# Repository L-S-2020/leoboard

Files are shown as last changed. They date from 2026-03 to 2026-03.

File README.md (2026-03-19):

# Leoboard
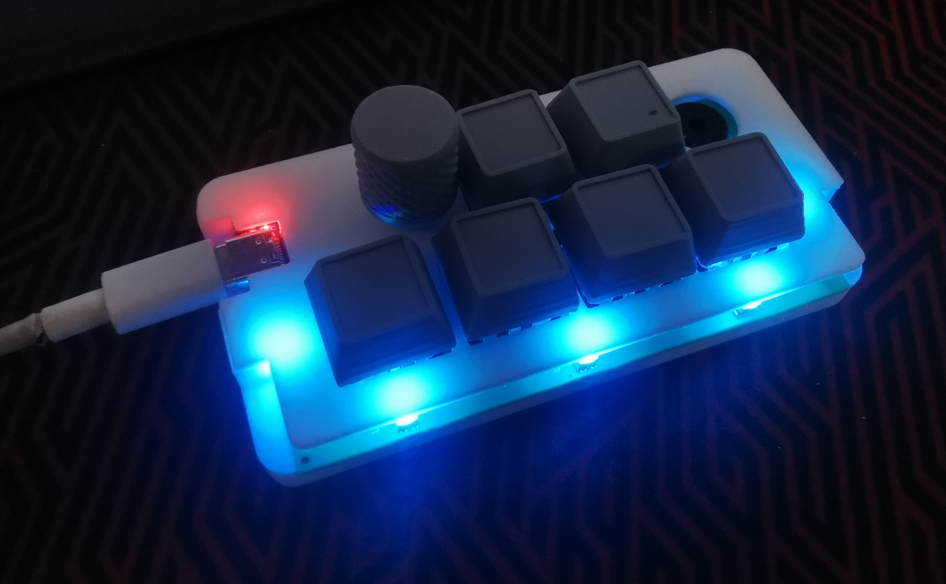
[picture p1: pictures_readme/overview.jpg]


A makroboard I designed as a christmas present and my first project using 3d printing / cad design.
You can find the case design on onshape under: 
https://cad.onshape.com/documents/f016138659585157d187dc39/w/5da7c9f47346b58de636040e/e/736dc8079a6dc26abaf89305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

## Features
- 6 MX Style switches
- buzzer (for sound)
- rotary encoder
- rgb leds 
- rp2040 based

Note: The code folder also includes kmk and the necessary addons, so it can be directly flashed to the rp2040.

## Standard key binds
The board has 3 switchable layers:
|Layer| Rotary button | Rotary encoder | Button 1 | Button 2 | Button 3 | Button 4 | Button 5 | Button 6 |
|--|--|--|--|--|--|--|--|--|
| 1 (normal) | Mute | Volume | Play/ Pause | Next song | Previous song | Win+Shift+S | Task manager | Lock pc |
|2 (gaming) |Discord mute| Volume | Mute | Discord audio off | Medal save clip | Screenshot | M | I |
|3 (premiere pro) | \ | Seek through frames | Add cut | Delete clip | Zoom in | Zoom out | Undo | Redo |
|Setings| must be hold down | -- | Layer 1 | Layer 2 | Layer 3 | LED on/off | LED breathe animation |LED rainbow animation |

## The story
One day as I was editing a video for the video club at my school (check out the [yt channel](https://www.youtube.com/@gsgwaldkirch4155)), I was annoyed by the standard key assignments of Premiere Pro. Especially using the arrow keys to seek through frames manually (i.e. for finding the excact startframe of a clip) is a really slow process, so I thought, wouldn't it be cool to have a rotary knob for that and then also to have a special key set for directly placing cuts and zooming in the timeline? 

So I the idea to design my own macroboard was born. I found a nice starting tutorial on [the hackclub blueprint website](https://blueprint.hackclub.com/), which showed the ground ideas of macroboard design.
As it was just two weeks before christmas back then, I thought it would also be cool to use the board as a christmas present.

So I got started with the pcb design using kicad. The design itself is based on the seed xiao rp2040 devboard, as it is the perfect size and also quite cheap. Additionally to my initial requirements (switches and rotary encoder), I came up with the idea to also add leds for light and a buzzer for playing startup sounds.

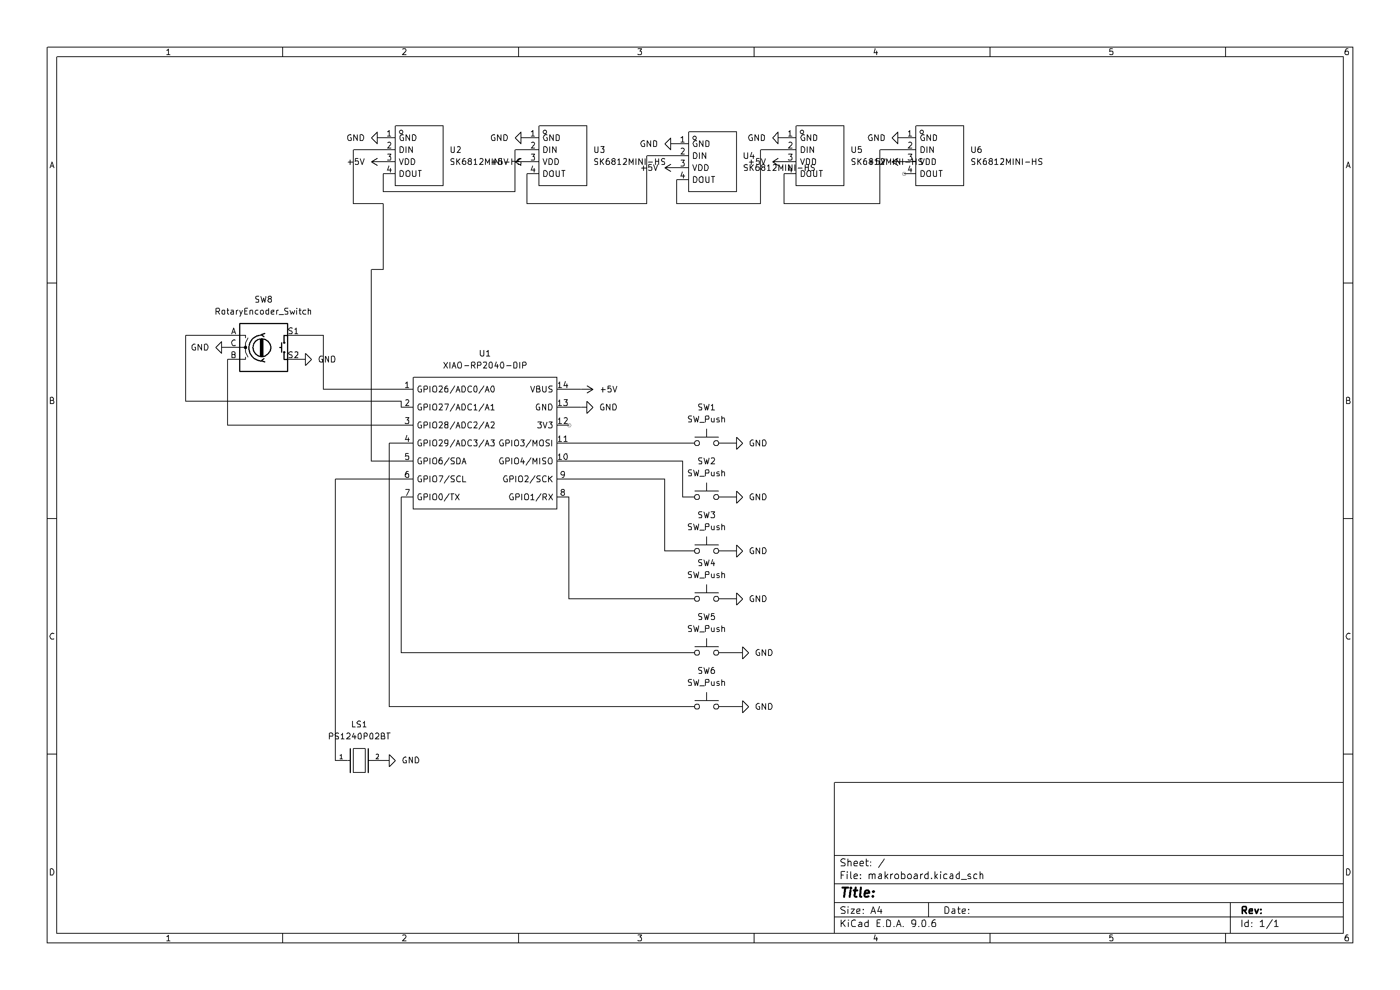
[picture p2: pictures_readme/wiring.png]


Then I designed the pcb board and searched in the jlcpcb parts library for suiting (and cheap) parts. 

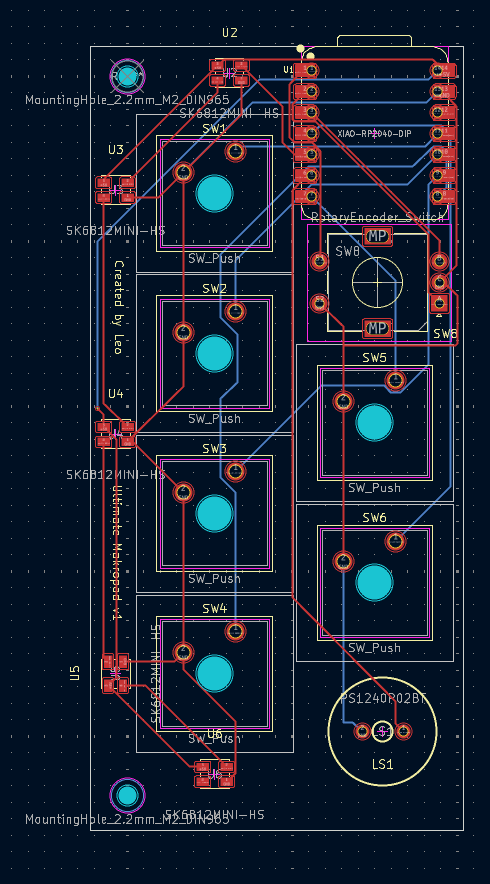
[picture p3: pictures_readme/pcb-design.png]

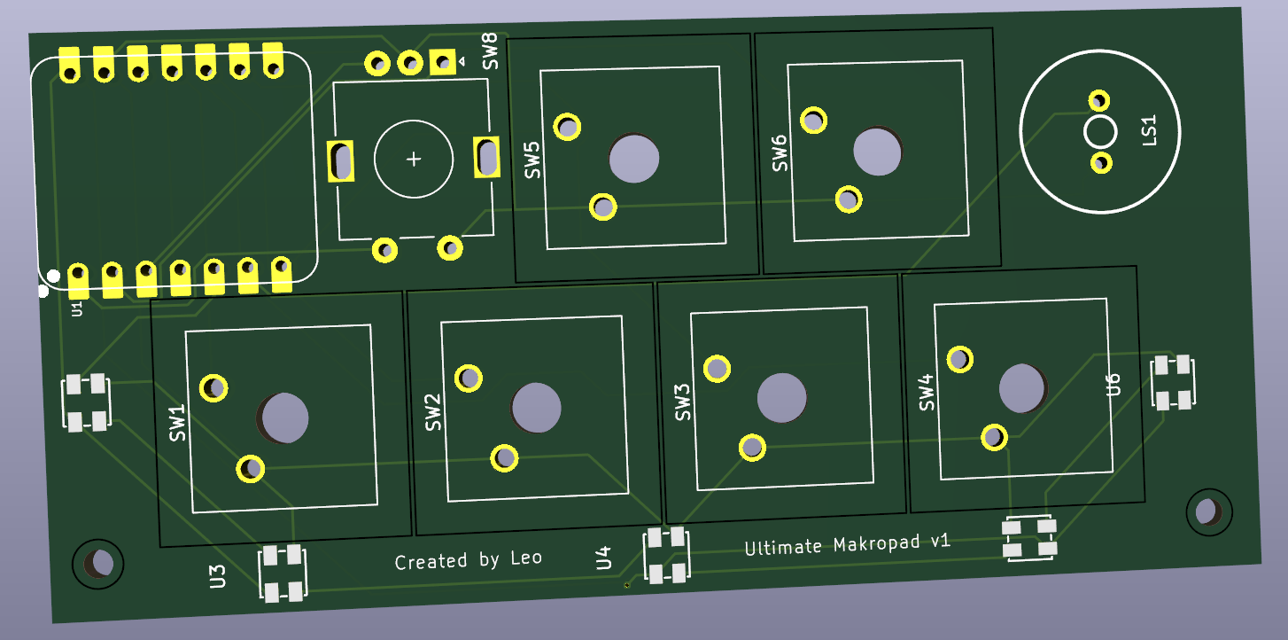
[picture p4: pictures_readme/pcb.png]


As the order was on its way, I started designing the case using onshape.

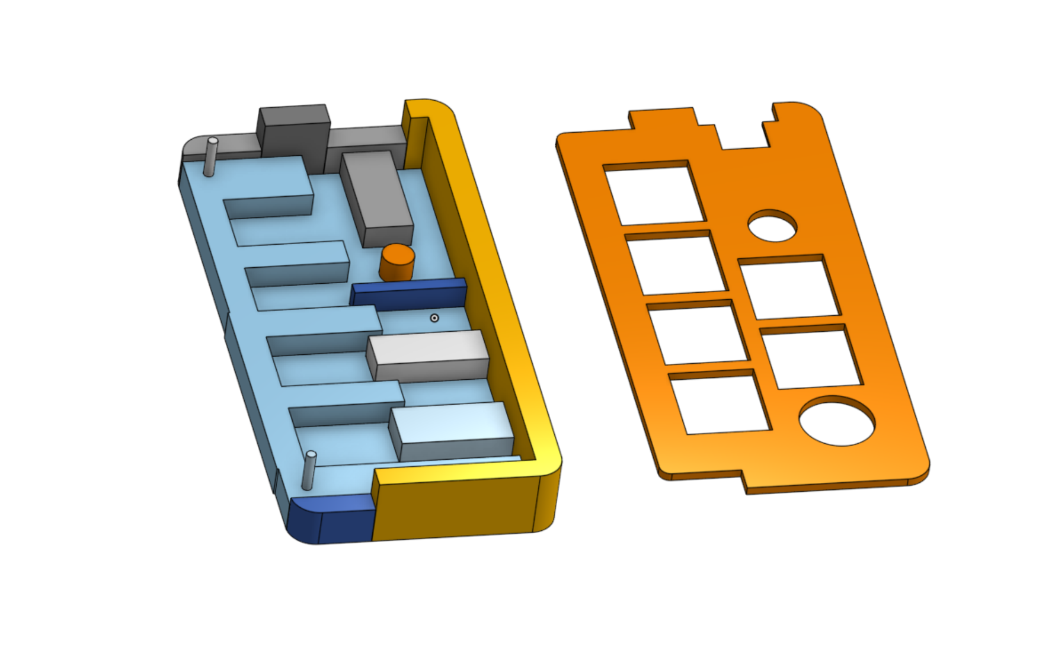
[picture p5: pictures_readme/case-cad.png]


I also created an assembled model in onshape, to test the dimensions.

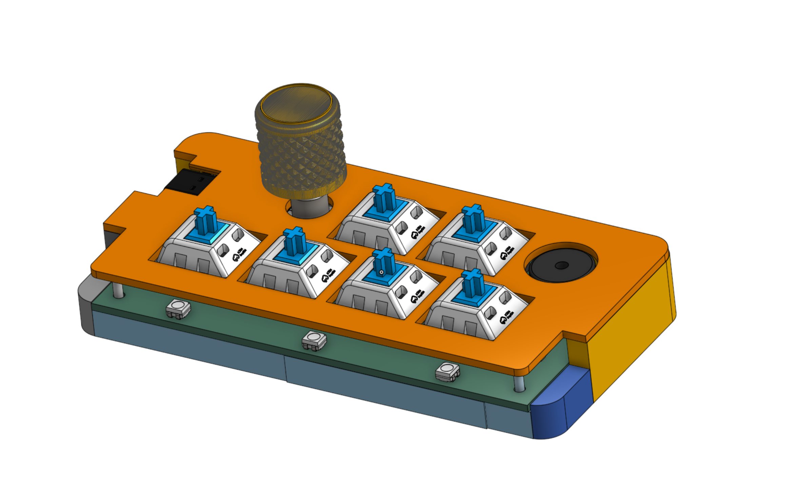
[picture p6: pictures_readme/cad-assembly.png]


After printing and assembling the final macropads, I learned that, it's not good to make the inner dimensions of your case exactly like the dimensions of your board ;) , but fortunately, I printed everything in pla, so after some heating using a hair dryer, I could fit the pcb inside.

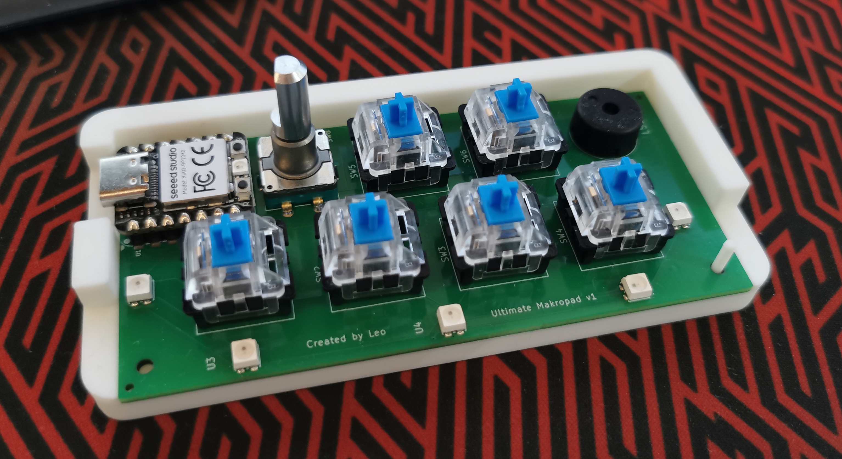
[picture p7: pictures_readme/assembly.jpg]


I then wrote a script for it, using kmk, as I liked the idea of being able to quickly change some configurations, without having to recompile. 
[@SillyGoose123](https://github.com/SillyGoose123) is also currently working on a more powerful, rust-based firmware for the board with a web based settings interface, check it out [here](https://github.com/SillyGoose123/MacroBoard).

##
A big thanks to my cs teacher for letting me print out the cases using the 3dprinter in his office and to [@SillyGoose123](https://github.com/SillyGoose123) for printing out the keycaps.

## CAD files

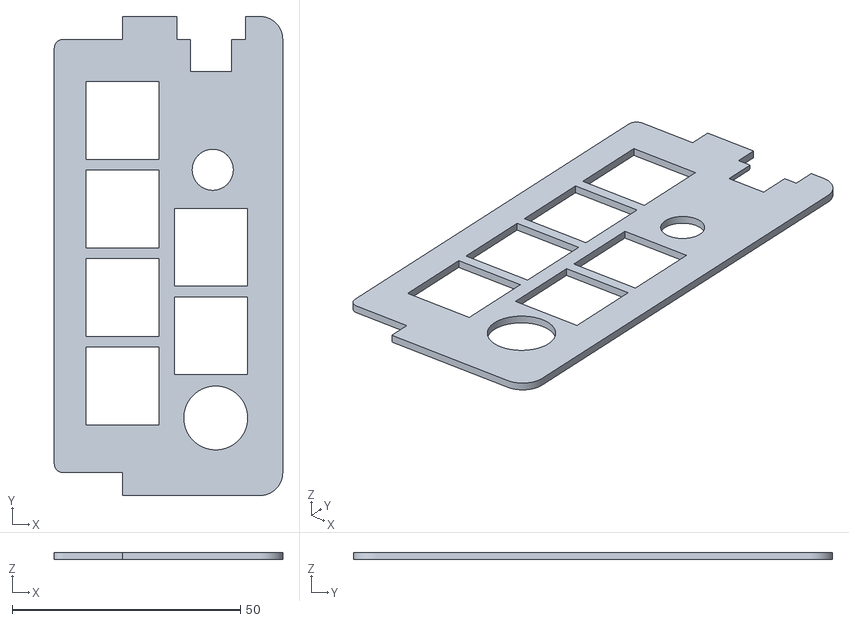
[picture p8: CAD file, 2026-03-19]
cad/top.stl
50.1 x 105.0 x 1.60

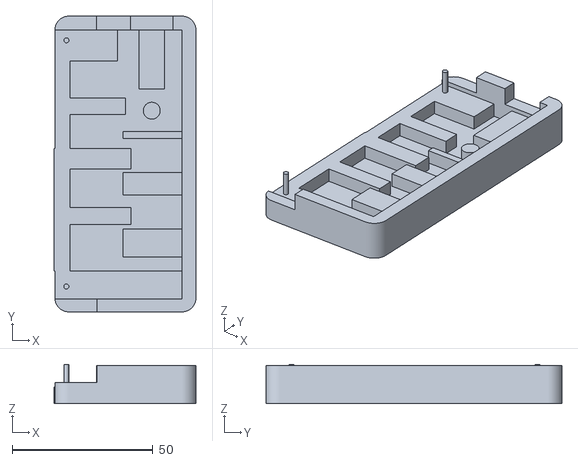
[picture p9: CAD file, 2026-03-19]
cad/bottom.stl
50.4 x 105.0 x 14.0

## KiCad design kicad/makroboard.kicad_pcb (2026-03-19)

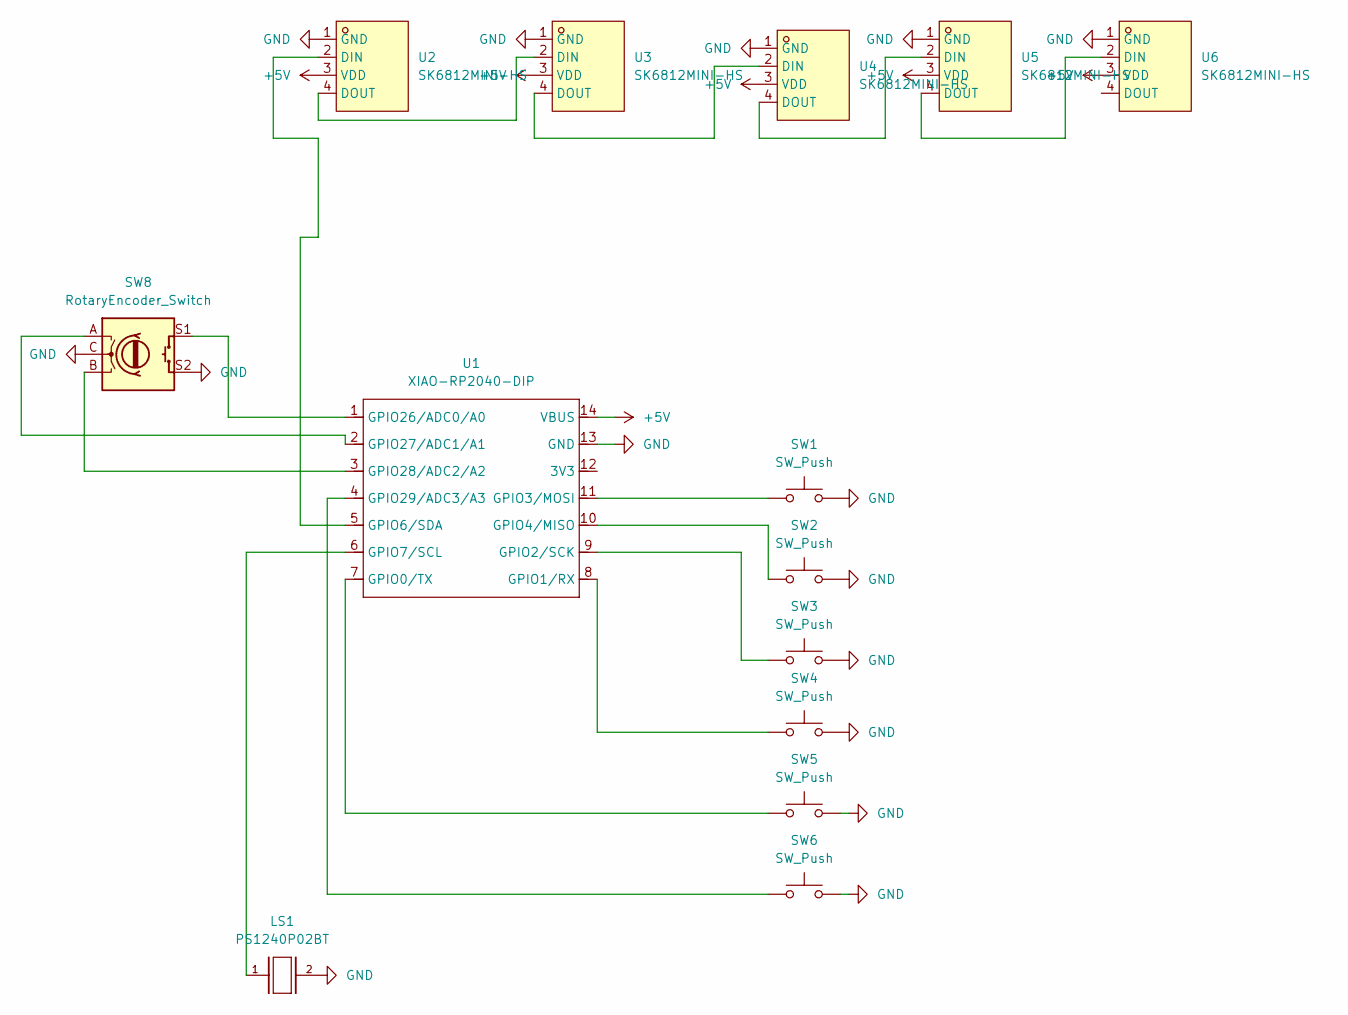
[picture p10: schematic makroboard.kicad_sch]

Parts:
LS1: PS1240P02BT; XDCR_PS1240P02BT
SW1, SW2, SW3, SW4, SW5, SW6: SW_Push; SW_Cherry_MX_1.00u_Plate
SW8: RotaryEncoder_Switch; RotaryEncoder_Alps_EC11E-Switch_Vertical_H20mm
U1: XIAO-RP2040-DIP
U2, U3, U4, U5, U6: SK6812MINI-HS; LED-SMD_4P-L3.5-W3.5-BR_SK6812MINI-HS; LCSC Part C2922787

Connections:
+5V: U1.14 (VBUS), U2.3 (VDD), U3.3 (VDD), U4.3 (VDD), U5.3 (VDD), U6.3 (VDD)
GND: LS1.2, SW1.2, SW2.2, SW3.2, SW4.2, SW5.2, SW6.2, SW8.C, SW8.S2, U1.13 (GND), U2.1 (GND), U3.1 (GND), U4.1 (GND), U5.1 (GND), U6.1 (GND)
unnamed: SW5.1, U1.7 (GPIO0/TX)
unnamed: SW4.1, U1.8 (GPIO1/RX)
unnamed: SW3.1, U1.9 (GPIO2/SCK)
unnamed: SW1.1, U1.11 (GPIO3/MOSI)
unnamed: SW2.1, U1.10 (GPIO4/MISO)
unnamed: U1.5 (GPIO6/SDA), U2.2 (DIN)
unnamed: LS1.1, U1.6 (GPIO7/SCL)
unnamed: SW8.S1, U1.1 (GPIO26/ADC0/A0)
unnamed: SW8.A, U1.2 (GPIO27/ADC1/A1)
unnamed: SW8.B, U1.3 (GPIO28/ADC2/A2)
unnamed: SW6.1, U1.4 (GPIO29/ADC3/A3)
unnamed: U2.4 (DOUT), U3.2 (DIN)
unnamed: U3.4 (DOUT), U4.2 (DIN)
unnamed: U4.4 (DOUT), U5.2 (DIN)
unnamed: U5.4 (DOUT), U6.2 (DIN)

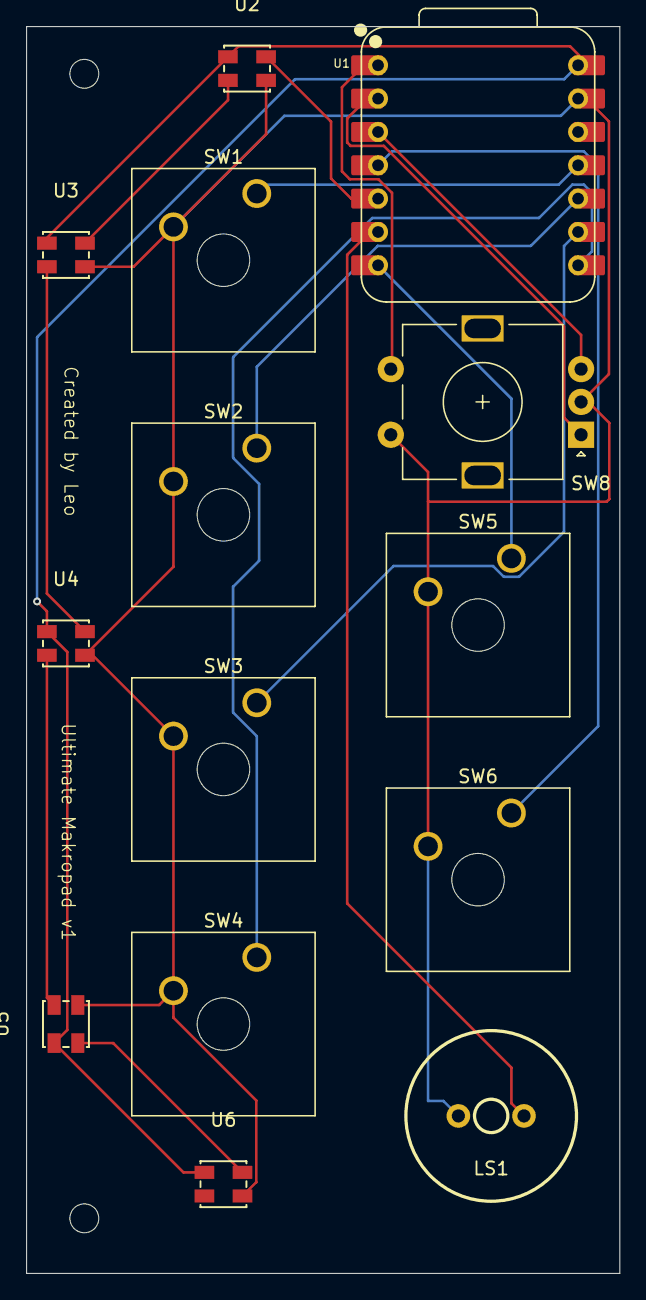
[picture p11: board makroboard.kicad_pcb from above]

Board: 2 copper layers, 45.2 x 95.0 mm, 15 parts (0 on the bottom side), 17 nets.

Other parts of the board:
MT: MountingHole_2.2mm_M2_DIN965

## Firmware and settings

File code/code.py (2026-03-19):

import time
import board
import digitalio
import pwmio

from kmk.kmk_keyboard import KMKKeyboard
from kmk.scanners.keypad import KeysScanner
from kmk.keys import KC
from kmk.modules.layers import Layers
from kmk.modules.macros import Macros
from kmk.modules.encoder import EncoderHandler
from kmk.extensions.media_keys import MediaKeys
from kmk.extensions.RGB import RGB
from kmk.extensions.rgb import AnimationModes
from kmk.extensions import Extension

# ---------------- Layer IDs ----------------
L_NORMAL   = 0
L_GAMING   = 1
L_PREMIERE = 2
L_FN       = 3

# ---------------- Buzzer (simple, reliable) ----------------
import time
import pwmio
from kmk.extensions import Extension

class _BuzzerPlayer:
    def __init__(self, pin, duty_on=2**15):
        self.pin = pin
        self.duty_on = duty_on
        self.pwm = None
        self.seq = None
        self.i = 0
        self.until = 0.0
        self.playing = False
        self._init_pwm()

    def _init_pwm(self):
        if self.pwm:
            try:
                self.pwm.deinit()
            except Exception:
                pass
        self.pwm = pwmio.PWMOut(self.pin, variable_frequency=True, duty_cycle=0)

    def stop(self):
        # hard stop
        try:
            self.pwm.duty_cycle = 0
        except Exception:
            pass
        self.playing = False
        self.seq = None
        self.i = 0

    def play(self, seq):
        self.seq = list(seq)
        self.i = 0
        self.playing = True
        self._start_step()

    def _start_step(self):
        if not self.seq or self.i >= len(self.seq):
            self.stop()
            return
        freq, dur_ms = self.seq[self.i]
        if freq and freq > 0:
            self.pwm.frequency = int(freq)
            self.pwm.duty_cycle = self.duty_on
        else:
            self.pwm.duty_cycle = 0
        self.until = time.monotonic() + dur_ms / 1000.0

    def tick(self):
        if not self.playing:
            return
        if time.monotonic() >= self.until:
            self.i += 1
            self._start_step()
    
    def after_matrix_scan(self, sandbox):
        return
    
    def before_hid_send(self, sandbox):
        return
        
    def after_hid_send(self, sandbox):
        return

def _beep(n, freq=2200, on_ms=55, off_ms=55):
    out = []
    for k in range(n):
        out.append((freq, on_ms))
        if k != n - 1:
            out.append((0, off_ms))
    return out

def _startup():
    return [(1600, 40), (0, 25), (2400, 60), (0, 20)]

class LayerLEDs(Extension):
    def __init__(self, led_r, led_g, led_b, active_low=True):
        self.led_r, self.led_g, self.led_b = led_r, led_g, led_b
        self.active_low = active_low
        self.last = None

    def during_bootup(self, keyboard):
        # must exist or extension gets removed [page:0]
        self._all_off()

    def _on(self, led):
        led.value = False if self.active_low else True

    def _off(self, led):
        led.value = True if self.active_low else False

    def _all_off(self):
        self._off(self.led_r)
        self._off(self.led_g)
        self._off(self.led_b)

    def _set(self, base):
        self._all_off()
        if base == 0:
            self._on(self.led_r)
        elif base == 1:
            self._on(self.led_g)
        elif base == 2:
            self._on(self.led_b)

    def before_matrix_scan(self, sandbox):
        # sandbox.active_layers is refreshed every loop [page:0]
        layers = sandbox.active_layers or [0]
        base_candidates = [l for l in layers if l in (0, 1, 2)]
        base = max(base_candidates) if base_candidates else 0
        if base != self.last:
            self.last = base
            self._set(base)
    
    def after_matrix_scan(self, sandbox):
        return
    
    def before_hid_send(self, sandbox):
        return
        
    def after_hid_send(self, sandbox):
        return

class BuzzerSounds(Extension):
    def __init__(self, buzzer_pin):
        self.player = _BuzzerPlayer(buzzer_pin)
        self.last_base = None
        self.did_startup = False

    def during_bootup(self, keyboard):
        # must exist or extension gets removed [page:0]
        self.player.stop()
        self.last_base = None
        self.did_startup = False

    def before_matrix_scan(self, sandbox):
        # Always tick audio here (runs each loop) [page:0]
        self.player.tick()

        # Start-up sound once (first loop after boot)
        if not self.did_startup:
            self.did_startup = True
            self.player.play(_startup())
            return

        # Layer-change sound (base layer only)
        layers = sandbox.active_layers or [0]
        base_candidates = [l for l in layers if l in (0, 1, 2)]
        base = max(base_candidates) if base_candidates else 0

        if base != self.last_base:
            self.last_base = base
            self.player.play(_beep(base + 1))
    
    def after_matrix_scan(self, sandbox):
        return
    
    def before_hid_send(self, sandbox):
        return
        
    def after_hid_send(self, sandbox):
        return



import board
import digitalio

from kmk.kmk_keyboard import KMKKeyboard
from kmk.scanners.keypad import KeysScanner
from kmk.keys import KC
from kmk.modules.layers import Layers
from kmk.modules.macros import Press, Release, Tap, Macros
from kmk.modules.encoder import EncoderHandler
from kmk.extensions.media_keys import MediaKeys
from kmk.extensions.RGB import RGB

# ---------------- Layers ----------------
L_NORMAL   = 0
L_GAMING   = 1
L_PREMIERE = 2
L_FN       = 3

# ---------------- Macros ----------------
macros = Macros()

WIN_SHIFT_S = KC.MACRO(
    Press(KC.LGUI),
    Press(KC.LSFT),
    Tap(KC.S),
    Release(KC.LSFT),
    Release(KC.LGUI),
)

TASK_MANAGER = KC.MACRO(
    Press(KC.LCTL),
    Press(KC.LSFT),
    Tap(KC.ESC),
    Release(KC.LSFT),
    Release(KC.LCTL),
)

LOCK_PC = KC.MACRO(
    Press(KC.LGUI),
    Tap(KC.L),
    Release(KC.LGUI),
)

CTRL_SHIFT_M = KC.MACRO(
    Press(KC.LCTL),
    Press(KC.LSFT),
    Tap(KC.M),
    Release(KC.LSFT),
    Release(KC.LCTL),
)

CTRL_SHIFT_D = KC.MACRO(
    Press(KC.LCTL),
    Press(KC.LSFT),
    Tap(KC.D),
    Release(KC.LSFT),
    Release(KC.LCTL),
)

ALT_F10 = KC.MACRO(
    Press(KC.LALT),
    Tap(KC.F10),
    Release(KC.LALT),
)

CTRL_K = KC.MACRO(
    Press(KC.LCTL),
    Tap(KC.K),
    Release(KC.LCTL),
)

SHIFT_DELETE = KC.MACRO(
    Press(KC.LSFT),
    Tap(KC.DEL),
    Release(KC.LSFT),
)

CTRL_Z = KC.MACRO(
    Press(KC.LCTL),
    Tap(KC.Z),
    Release(KC.LCTL),
)

CTRL_SHIFT_Z = KC.MACRO(
    Press(KC.LCTL),
    Press(KC.LSFT),
    Tap(KC.Z),
    Release(KC.LSFT),
    Release(KC.LCTL),
)

# ---------------- Keyboard Setup ----------------
keyboard = KMKKeyboard()
keyboard.modules.append(macros)
keyboard.modules.append(Layers())
keyboard.extensions.append(MediaKeys())

encoder_handler = EncoderHandler()
keyboard.modules.append(encoder_handler)

rgb = RGB(pixel_pin=board.D4, num_pixels=5, animation_mode=AnimationModes.RAINBOW, val_default=30)
keyboard.extensions.append(rgb)

# 3 one-color LEDs
led_blue = digitalio.DigitalInOut(board.LED_BLUE); led_blue.direction = digitalio.Direction.OUTPUT
led_green = digitalio.DigitalInOut(board.LED_GREEN); led_green.direction = digitalio.Direction.OUTPUT
led_red = digitalio.DigitalInOut(board.LED_RED); led_red.direction = digitalio.Direction.OUTPUT

keyboard.extensions.append(LayerLEDs(led_red, led_green, led_blue, active_low=True))
keyboard.extensions.append(BuzzerSounds(board.D5))

# Keys: encoder button is wired as key on D0
PINS = [board.D0, board.D3, board.D6, board.D7, board.D8, board.D9, board.D10]
keyboard.matrix = KeysScanner(pins=PINS, value_when_pressed=False)

# Encoder A/B only; click handled by key on D0
encoder_handler.pins = ((board.D1, board.D2, None, False, 2),)

# ---------------- FN + Button combos for layer switching ----------------
# We implement cycling on FN layer by direct TO() targets:
# FN + Button1 -> Normal, FN + Button2 -> Gaming, FN + Button3 -> Premiere
# (This is robust and avoids needing to track current state.)
FN_TO_NORMAL   = KC.TO(L_NORMAL)
FN_TO_GAMING   = KC.TO(L_GAMING)
FN_TO_PREMIERE = KC.TO(L_PREMIERE)

# ---------------- Encoder click: LT(FN, <tap>) per layer ----------------
ENC_BTN_NORMAL   = KC.LT(L_FN, KC.MUTE)
ENC_BTN_GAMING   = KC.LT(L_FN, CTRL_SHIFT_M)
ENC_BTN_PREMIERE = KC.LT(L_FN, KC.BSLS)  # "\"

# ---------------- Keymaps ----------------
# Order per layer: [ENC_BTN, B1, B2, B3, B4, B5, B6]
keyboard.keymap = [
    # Layer 1: Normal
    [
        ENC_BTN_NORMAL,
        KC.MPLY,      # Play/Pause [web:199]
        KC.MNXT,      # Next [web:199]
        KC.MPRV,      # Prev [web:199]
        WIN_SHIFT_S,  # Win+Shift+S [web:148]
        TASK_MANAGER, # Ctrl+Shift+Esc [web:148]
        LOCK_PC,      # Win+L [web:148]
    ],

    # Layer 2: Gaming
    [
        ENC_BTN_GAMING,
        CTRL_SHIFT_M, # Discord mute toggle
        CTRL_SHIFT_D, # Discord deafen
        ALT_F10,      # Shadowplay instant replay
        KC.F12,       # Steam screenshot
        KC.M,         # Map
        KC.I,         # Inventory
    ],

    # Layer 3: Premiere
    [
        ENC_BTN_PREMIERE,
        CTRL_K,        # Add Edit
        SHIFT_DELETE,  # Ripple delete
        KC.RBRC,    # Zoom In
        KC.SLSH,   # Zoom out (-)
        CTRL_Z,        # Undo
        CTRL_SHIFT_Z,  # Redo
    ],

    # FN layer: layer select + RGB controls (optional)
    [
        KC.TRNS,        # keep LT hold
        FN_TO_NORMAL,   # FN + Button1 -> Normal
        FN_TO_GAMING,   # FN + Button2 -> Gaming
        FN_TO_PREMIERE, # FN + Button3 -> Premiere
        KC.RGB_TOG,          # FN + Button4 -> Static RGB
        KC.RGB_MODE_BREATHE,        # FN + Button5 -> Breathing
        KC.RGB_MODE_RAINBOW,
    ],
]

# ---------------- Encoder rotation per layer ----------------
# tuple: (CCW, CW, Click) and Click is unused because click is on D0 key [web:146]
encoder_handler.map = [
    ((KC.VOLD, KC.VOLU, KC.NO),),     # Normal: volume
    ((KC.VOLD, KC.VOLU, KC.NO),),     # Gaming: fallback volume (replace with brightness/discord vol if you add software)
    ((KC.LEFT, KC.RIGHT, KC.NO),),    # Premiere: frame step
    ((KC.NO, KC.NO, KC.NO),),         # FN layer: do nothing
]
print(dir(rgb))
if __name__ == '__main__':
    keyboard.go()
